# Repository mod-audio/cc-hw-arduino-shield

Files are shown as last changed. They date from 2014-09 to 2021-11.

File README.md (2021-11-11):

control-chain-arduino-shield
============================

This repository contains the schematics and PCB design files for Control Chain Arduino Shield hardware. It serves as a way for people to create new peripheral to be used in conjunction with MOD (http://moddevices.com/) via its Control Chain interface.

These files were created and can be improved with KiCAD, a free software Electronics CAD which is available at http://www.kicad.org/

## Check out instructions ##

This project uses a set of KiCAD symbols and footprints provided by the official KiCad library (https://github.com/KiCad/). In order to properly fetch these dependencies, which are configured as submodule repositories, you have to use the **--recursive** attribute in the following **git** command:

> git clone --recursive https://github.com/portalmod/control-chain-arduino-shield.git

## Licensing ##

This is an Open Hardware project and all of the files in this repository are licensed under the terms of the "Creative Commons By-SA" license.

## Sample Code / Arduino Library ##

There is an Arduino library for making it easy to develop your own Control Chain peripherals freely available at https://github.com/portalmod/control-chain-arduino-lib

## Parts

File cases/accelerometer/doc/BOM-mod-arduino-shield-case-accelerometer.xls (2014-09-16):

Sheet: BOM
VALUE | QTD(x1) | PACKAGE | DESCRIPTION | MANUFACTURER | PART NUMBER
MISC
Accelerometer_MPU6050 | 1 | - | GY-521 MPU6050 3-Axis Acceleration Gyroscope 6DOF Module - Blue | - | http://www.dx.com/p/gy-521-mpu6050-3-axis-acceleration-gyroscope-6dof-module-blue-154602

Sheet: KiCAD
Item | Qty | Reference(s) | Value | LibPart | Footprint | Datasheet
1 | 2 | AD1, AD_PROTO1 | HEADER_1x6 | MODuino_Control_Chain:HEADER_1x6 | HEADER_100MIL_1R6P_PTH
2 | 3 | C1, C7, C9 | 100uF | device:CP1 | CAP_RAD_5MM
3 | 6 | C2, C3, C4, C5, C6, C8 | 100nF | device:C | SM0805
4 | 1 | D1 | CGRA4007-G | device:DIODE | DO-214AC(SMA)
5 | 2 | D2, D3 | MMSZ5242B | device:ZENERsmall | SOD123
6 | 2 | H1, H2 | HOLE | conn:CONN_1 | HOLE_3MM
7 | 2 | IOH1, IOH_PROTO1 | HEADER_1x10 | MODuino_Control_Chain:HEADER_1x10 | HEADER_100MIL_1R10P_PTH
8 | 4 | IOL1, IOL_PROTO1, POWER1, POWER_PROTO1 | HEADER_1x8 | MODuino_Control_Chain:HEADER_1x8 | HEADER_100MIL_1R8P_PTH
9 | 2 | J1, J2 | RJHSE-5084 | MODuino_Control_Chain:RJ45_CHAIN | RJ45-RJHSE5084
10 | 1 | JP1 | HEADER_2x3_180 | MODuino_Control_Chain:HEADER_2x3 | HEADER_100MIL_2R3P_PTH
11 | 1 | PROTOBOARD1 | PROTO_8x16 | MODuino_Control_Chain:PROTO_8x16 | PROTOBOARD_100MIL_8R16P_PTH
12 | 3 | PROTO_3.3V1, PROTO_5V1, PROTO_GND1 | HEADER_1x16 | MODuino_Control_Chain:HEADER_1x16 | PROTOBOARD_100MIL_1R16P_PTH
13 | 2 | Q1, Q2 | MMBT3904 | device:NPN | SOT23
14 | 1 | R1 | 120R | device:R | SM0805
15 | 4 | R10, R4, R5, R9 | 1k | device:R | SM0805
16 | 4 | R11, R12, R13, R14 | 470R | device:R | SM0805
17 | 2 | R2, R3 | 10R | device:R | SM0805
18 | 3 | R6, R7, R8 | 10k | device:R | SM0805
19 | 1 | RT1 | FUSE_500mA | device:FUSE | SM2920
20 | 1 | U1 | SN75176BDR | MODuino_Control_Chain:SN75176BDR | SO8E

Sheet: KiCAD Organized
Value | Qty | Reference(s) | Footprint
CAPACITOR
100nF | 6 | C2, C3, C4, C5, C6, C8 | SM0805
100uF | 3 | C1, C7, C9 | CAP_RAD_5MM
RESISTOR
10R | 2 | R2, R3 | SM0805
120R | 1 | R1 | SM0805
470R | 4 | R11, R12, R13, R14 | SM0805
1k | 4 | R10, R4, R5, R9 | SM0805
10k | 3 | R6, R7, R8 | SM0805
DIODE
CGRA4007-G | 1 | D1 | DO-214AC(SMA)
MMSZ5242B | 2 | D2, D3 | SOD123
TRANSISTOR
MMBT3904 | 2 | Q1, Q2 | SOT23
IC
SN75176BDR | 1 | U1 | SO8E
MISC
FUSE_500mA | 1 | RT1 | SM1210
CONNECTOR
HEADER_1x6 | 2 | AD1, AD_PROTO1 | HEADER_100MIL_1R6P_PTH
HEADER_1x10 | 2 | IOH1, IOH_PROTO1 | HEADER_100MIL_1R10P_PTH
HEADER_1x8 | 4 | IOL1, IOL_PROTO1, POWER1, POWER_PROTO1 | HEADER_100MIL_1R8P_PTH
RJHSE-5084 | 2 | J1, J2 | RJ45-RJHSE5084
HEADER_2x3_180 | 1 | JP1 | HEADER_100MIL_2R3P_PTH
PROTO_8x16 | 1 | PROTOBOARD1 | PROTOBOARD_100MIL_8R16P_PTH
HEADER_1x16 | 3 | PROTO_3.3V1, PROTO_5V1, PROTO_GND1 | PROTOBOARD_100MIL_1R16P_PTH

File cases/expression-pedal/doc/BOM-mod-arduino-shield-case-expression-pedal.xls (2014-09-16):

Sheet: BOM
VALUE | QTD(x1) | PACKAGE | DESCRIPTION | MANUFACTURER | PART NUMBER
RESISTOR
100R | 3 | 0.091" Dia x 0.256" L (2.30mm x 6.50mm) | RES 100 OHM 1/4W 5% CARBON FILM | Stackpole Eletronics Inc | CF14JT100R (http://www.digikey.com/product-detail/en/CF14JT100R/CF14JT100RCT-ND/1830327)
10k | 1 | 0.091" Dia x 0.256" L (2.30mm x 6.50mm) | RES 10K OHM 1/4W 5% CARBON FILM | Stackpole Eletronics Inc | CF14JT10K0 (http://www.digikey.com/product-detail/en/CF14JT10K0/CF14JT10K0CT-ND/1830374)
POT 10k | 1 | Round - 0.669" Dia x 0.374" L (17.00mm x 9.50mm) | POT ROTARY 10K OHM 16MM PC PIN | TT Eletronics/BI | P160KN2-4QC20B10K (http://www.digikey.com/product-detail/en/P160KN2-4QC20B10K/987-1310-ND/2408887)
MISC
Switch Button | 1 | Through Hole | Pushbutton Switches DPDT STOMP/FOOT SW LATCH 4A30VDC 9LUG | Alpha | SF12020F-0202-20R-L-011 (http://br.mouser.com/ProductDetail/Alpha-Taiwan/SF12020F-0202-20R-L-011/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)

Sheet: KiCAD
Item | Qty | Reference(s) | Value | LibPart | Footprint | Datasheet
1 | 2 | AD1, AD_PROTO1 | HEADER_1x6 | MODuino_Control_Chain:HEADER_1x6 | HEADER_100MIL_1R6P_PTH
2 | 3 | C1, C7, C9 | 100uF | device:CP1 | CAP_RAD_5MM
3 | 6 | C2, C3, C4, C5, C6, C8 | 100nF | device:C | SM0805
4 | 1 | D1 | CGRA4007-G | device:DIODE | DO-214AC(SMA)
5 | 2 | D2, D3 | MMSZ5242B | device:ZENERsmall | SOD123
6 | 2 | H1, H2 | HOLE | conn:CONN_1 | HOLE_3MM
7 | 2 | IOH1, IOH_PROTO1 | HEADER_1x10 | MODuino_Control_Chain:HEADER_1x10 | HEADER_100MIL_1R10P_PTH
8 | 4 | IOL1, IOL_PROTO1, POWER1, POWER_PROTO1 | HEADER_1x8 | MODuino_Control_Chain:HEADER_1x8 | HEADER_100MIL_1R8P_PTH
9 | 2 | J1, J2 | RJHSE-5084 | MODuino_Control_Chain:RJ45_CHAIN | RJ45-RJHSE5084
10 | 1 | JP1 | HEADER_2x3_180 | MODuino_Control_Chain:HEADER_2x3 | HEADER_100MIL_2R3P_PTH
11 | 1 | PROTOBOARD1 | PROTO_8x16 | MODuino_Control_Chain:PROTO_8x16 | PROTOBOARD_100MIL_8R16P_PTH
12 | 3 | PROTO_3.3V1, PROTO_5V1, PROTO_GND1 | HEADER_1x16 | MODuino_Control_Chain:HEADER_1x16 | PROTOBOARD_100MIL_1R16P_PTH
13 | 2 | Q1, Q2 | MMBT3904 | device:NPN | SOT23
14 | 1 | R1 | 120R | device:R | SM0805
15 | 4 | R10, R4, R5, R9 | 1k | device:R | SM0805
16 | 4 | R11, R12, R13, R14 | 470R | device:R | SM0805
17 | 2 | R2, R3 | 10R | device:R | SM0805
18 | 3 | R6, R7, R8 | 10k | device:R | SM0805
19 | 1 | RT1 | FUSE_500mA | device:FUSE | SM2920
20 | 1 | U1 | SN75176BDR | MODuino_Control_Chain:SN75176BDR | SO8E

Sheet: KiCAD Organized
Value | Qty | Reference(s) | Footprint
CAPACITOR
100nF | 6 | C2, C3, C4, C5, C6, C8 | SM0805
100uF | 3 | C1, C7, C9 | CAP_RAD_5MM
RESISTOR
10R | 2 | R2, R3 | SM0805
120R | 1 | R1 | SM0805
470R | 4 | R11, R12, R13, R14 | SM0805
1k | 4 | R10, R4, R5, R9 | SM0805
10k | 3 | R6, R7, R8 | SM0805
DIODE
CGRA4007-G | 1 | D1 | DO-214AC(SMA)
MMSZ5242B | 2 | D2, D3 | SOD123
TRANSISTOR
MMBT3904 | 2 | Q1, Q2 | SOT23
IC
SN75176BDR | 1 | U1 | SO8E
MISC
FUSE_500mA | 1 | RT1 | SM1210
CONNECTOR
HEADER_1x6 | 2 | AD1, AD_PROTO1 | HEADER_100MIL_1R6P_PTH
HEADER_1x10 | 2 | IOH1, IOH_PROTO1 | HEADER_100MIL_1R10P_PTH
HEADER_1x8 | 4 | IOL1, IOL_PROTO1, POWER1, POWER_PROTO1 | HEADER_100MIL_1R8P_PTH
RJHSE-5084 | 2 | J1, J2 | RJ45-RJHSE5084
HEADER_2x3_180 | 1 | JP1 | HEADER_100MIL_2R3P_PTH
PROTO_8x16 | 1 | PROTOBOARD1 | PROTOBOARD_100MIL_8R16P_PTH
HEADER_1x16 | 3 | PROTO_3.3V1, PROTO_5V1, PROTO_GND1 | PROTOBOARD_100MIL_1R16P_PTH

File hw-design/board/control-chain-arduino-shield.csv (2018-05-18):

Item | Qty | Reference(s) | Value | LibPart | Footprint | Datasheet | MPN | Note
1 | 1 | C1 | 10uF | device:CP1 | Capacitors_SMD:c_elec_5x5.3 |  | UWX1E100MCL1GB
2 | 2 | C2, C3 | 100nF | device:C | Capacitors_SMD:C_0603 |  | C1608X7R1E104K080AA
3 | 1 | C4 | 10uF | device:C | Capacitors_SMD:C_0603 |  | GRM188R60G106ME47D
4 | 1 | D1 | CGRA4007-G | device:D | Diodes_SMD:Diode-SMA_Standard |  | CGRA4007-G
5 | 1 | D2 | LED | device:LED | LEDs:LED-0603 |  | LS Q976-NR-1
6 | 3 | D3, D4, D5 | 1N4148 | device:D | Diodes_SMD:SOD-323 |  | 1N4148WX-TP
7 | 1 | J1 | CC_MAIN | conn:RJ45 | local-footprints:54602-908LF |  | 54602-908LF
8 | 1 | J2 | CC_NEXT | conn:RJ45 | local-footprints:54602-908LF |  | 54602-908LF
9 | 1 | P1 | Power | conn:CONN_01X08 | Socket_Arduino_Uno:Socket_Strip_Arduino_1x08 |  | PREC008SFAN-RC
10 | 1 | P10 | Power | conn:CONN_01X08 | Socket_Arduino_Uno:Socket_Strip_Arduino_1x08 |  |  | no component
11 | 1 | P11 | Analog | conn:CONN_01X06 | Socket_Arduino_Uno:Socket_Strip_Arduino_1x06 |  |  | no component
12 | 1 | P12 | Digital | conn:CONN_01X10 | Socket_Arduino_Uno:Socket_Strip_Arduino_1x10 |  |  | no component
13 | 1 | P13 | Digital | conn:CONN_01X08 | Socket_Arduino_Uno:Socket_Strip_Arduino_1x08 |  |  | no component
14 | 5 | P14, P19, P20, P21, P9 | ~ | conn:CONN_01X14 | Socket_Arduino_Uno:Perfboard |  |  | no component
15 | 1 | P2 | Analog | conn:CONN_01X06 | Socket_Arduino_Uno:Socket_Strip_Arduino_1x06 |  | PREC006SFAN-RC
16 | 1 | P3 | Digital | conn:CONN_01X10 | Socket_Arduino_Uno:Socket_Strip_Arduino_1x10 |  | PREC010SFAN-RC
17 | 1 | P4 | Digital | conn:CONN_01X08 | Socket_Arduino_Uno:Socket_Strip_Arduino_1x08 |  | PREC008SFAN-RC
18 | 4 | P5, P6, P7, P8 | Hole | conn:CONN_01X01 | Socket_Arduino_Uno:Arduino_1pin |  |  | no component
19 | 2 | Q1, Q2 | 2N7002 | device:Q_NMOS_GSD | Housings_SOT-23_SOT-143_TSOT-6:SOT-23 |  | 2N7002P,215
20 | 1 | Q4 | IRFML8244TRPBF | device:Q_NMOS_GSD | Housings_SOT-23_SOT-143_TSOT-6:SOT-23 |  | IRFML8244TRPBF
21 | 1 | R1 | 330R | device:R | Resistors_SMD:R_0603 |  | RMCF0603JT330R
22 | 5 | R10, R11, R2, R4, R8 | 10K | device:R | Resistors_SMD:R_0603 |  | RMCF0603JT10K0
23 | 1 | R3 | 220K | device:R | Resistors_SMD:R_0603 |  | RMCF0603JT220K
24 | 1 | R9 | 100R | device:R | Resistors_SMD:R_0805 |  | ERJ-P06F1000V
25 | 1 | RT1 | PTC_FUSE | device:FUSE | Resistors_SMD:R_1210 |  | 0ZCB0050FF2G
26 | 1 | U1 | ISL83491 | interface:ISL83491 | Housings_SOIC:SOIC-14_3.9x8.7mm_Pitch1.27mm |  | ISL83491IBZ

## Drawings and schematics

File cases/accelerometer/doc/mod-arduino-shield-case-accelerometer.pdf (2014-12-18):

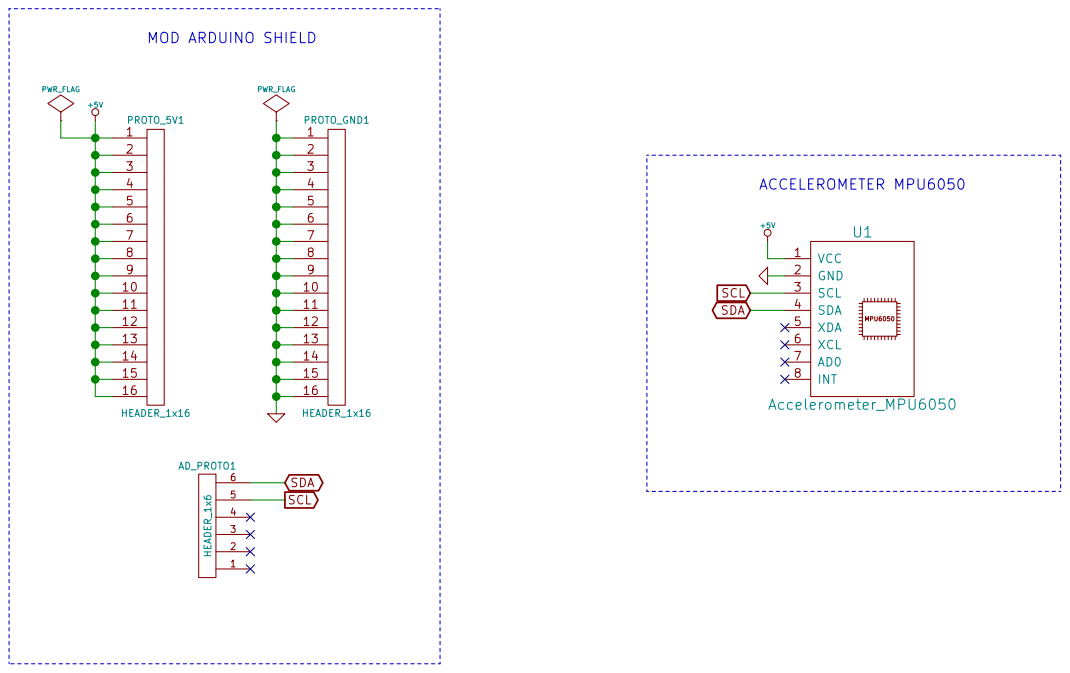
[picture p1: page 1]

File: mod-arduino-shield-case-accelerometer.sch Sheet: / http://portalmod.com/

Id: 1/1 Title: Accelerometer example circuit for the MOD Arduino Shield

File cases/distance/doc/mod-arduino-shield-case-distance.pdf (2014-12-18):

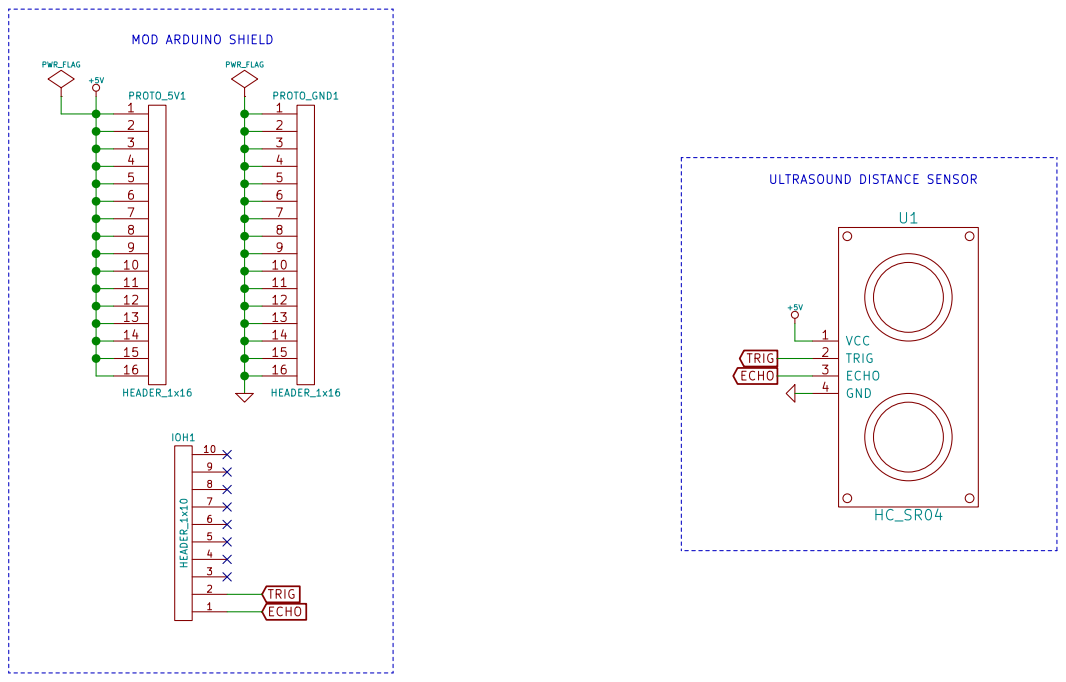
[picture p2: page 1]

ULTRASOUND DISTANCE SENSOR MOD ARDUINO SHIELD
PROTO_GND1 HEADER_1x16

File: mod-arduino-shield-case-distance.sch Sheet: / http://portalmod.com/

Id: 1/1 Title: Ultrasound Distance example circuit for the MOD Arduino Shield

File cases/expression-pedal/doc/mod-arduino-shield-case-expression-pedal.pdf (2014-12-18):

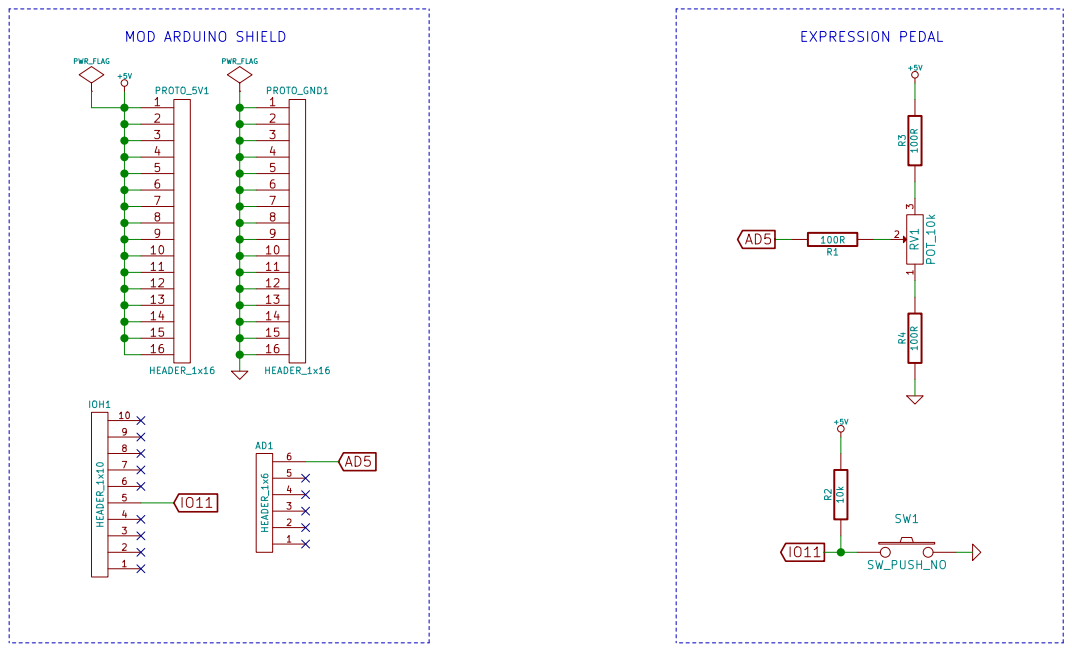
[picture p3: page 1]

File: mod-arduino-shield-case-expression-pedal.sch Sheet: / http://portalmod.com/

Id: 1/1 Title: Expression Pedal example circuit for the MOD Arduino Shield

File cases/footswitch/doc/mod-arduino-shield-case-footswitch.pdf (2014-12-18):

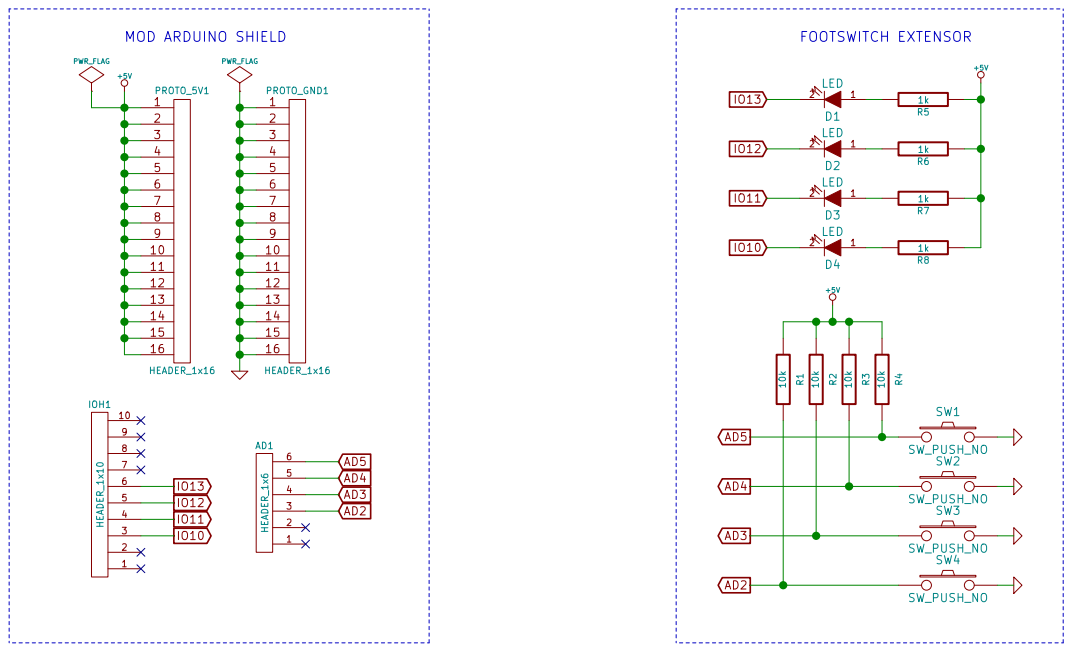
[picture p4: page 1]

File: mod-arduino-shield-case-footswitch.sch Sheet: / http://portalmod.com/

Id: 1/1 Title: Footswitch Extensor example circuit for the MOD Arduino Shield

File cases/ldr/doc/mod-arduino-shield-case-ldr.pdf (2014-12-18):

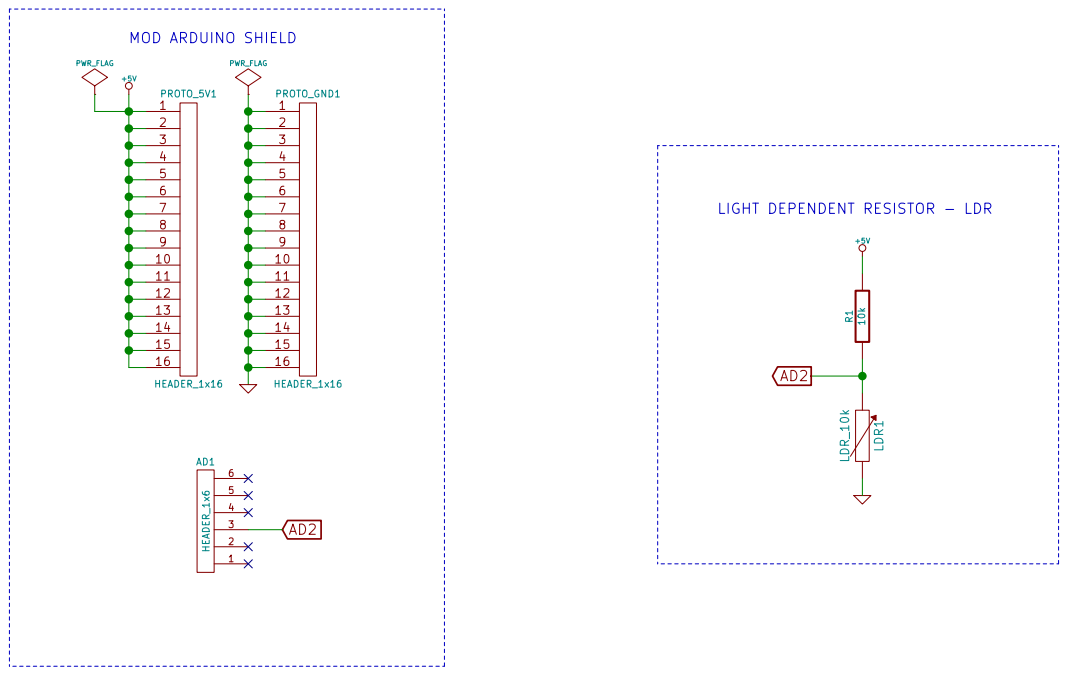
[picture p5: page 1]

LIGHT DEPENDENT RESISTOR - LDR LDR1 LDR_10k

File: mod-arduino-shield-case-ldr.sch Sheet: / http://portalmod.com/

Id: 1/1 Title: Light Sensor example circuit for the MOD Arduino Shield

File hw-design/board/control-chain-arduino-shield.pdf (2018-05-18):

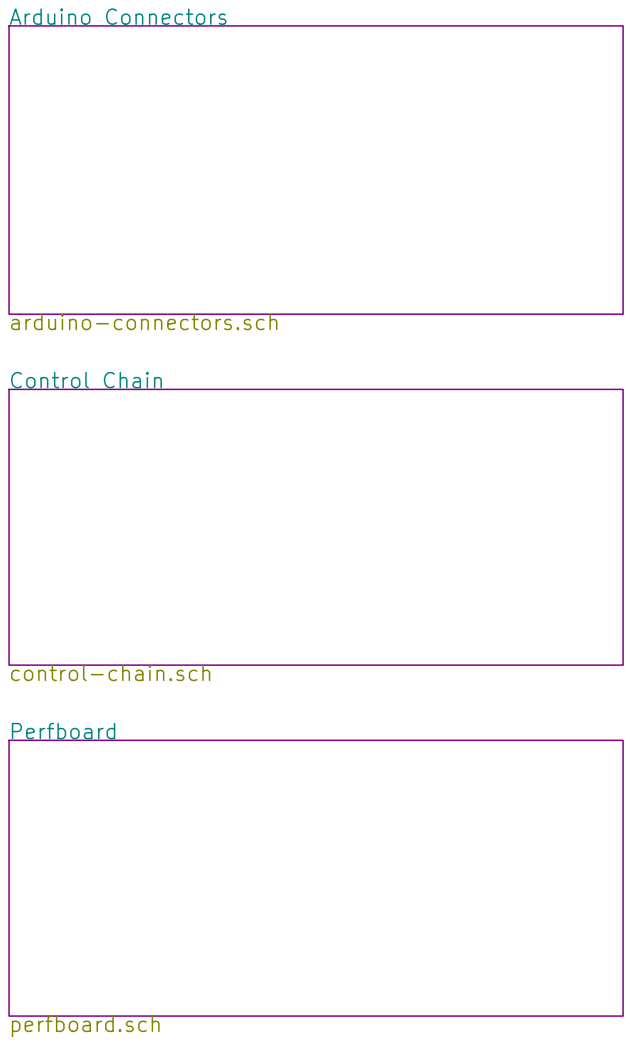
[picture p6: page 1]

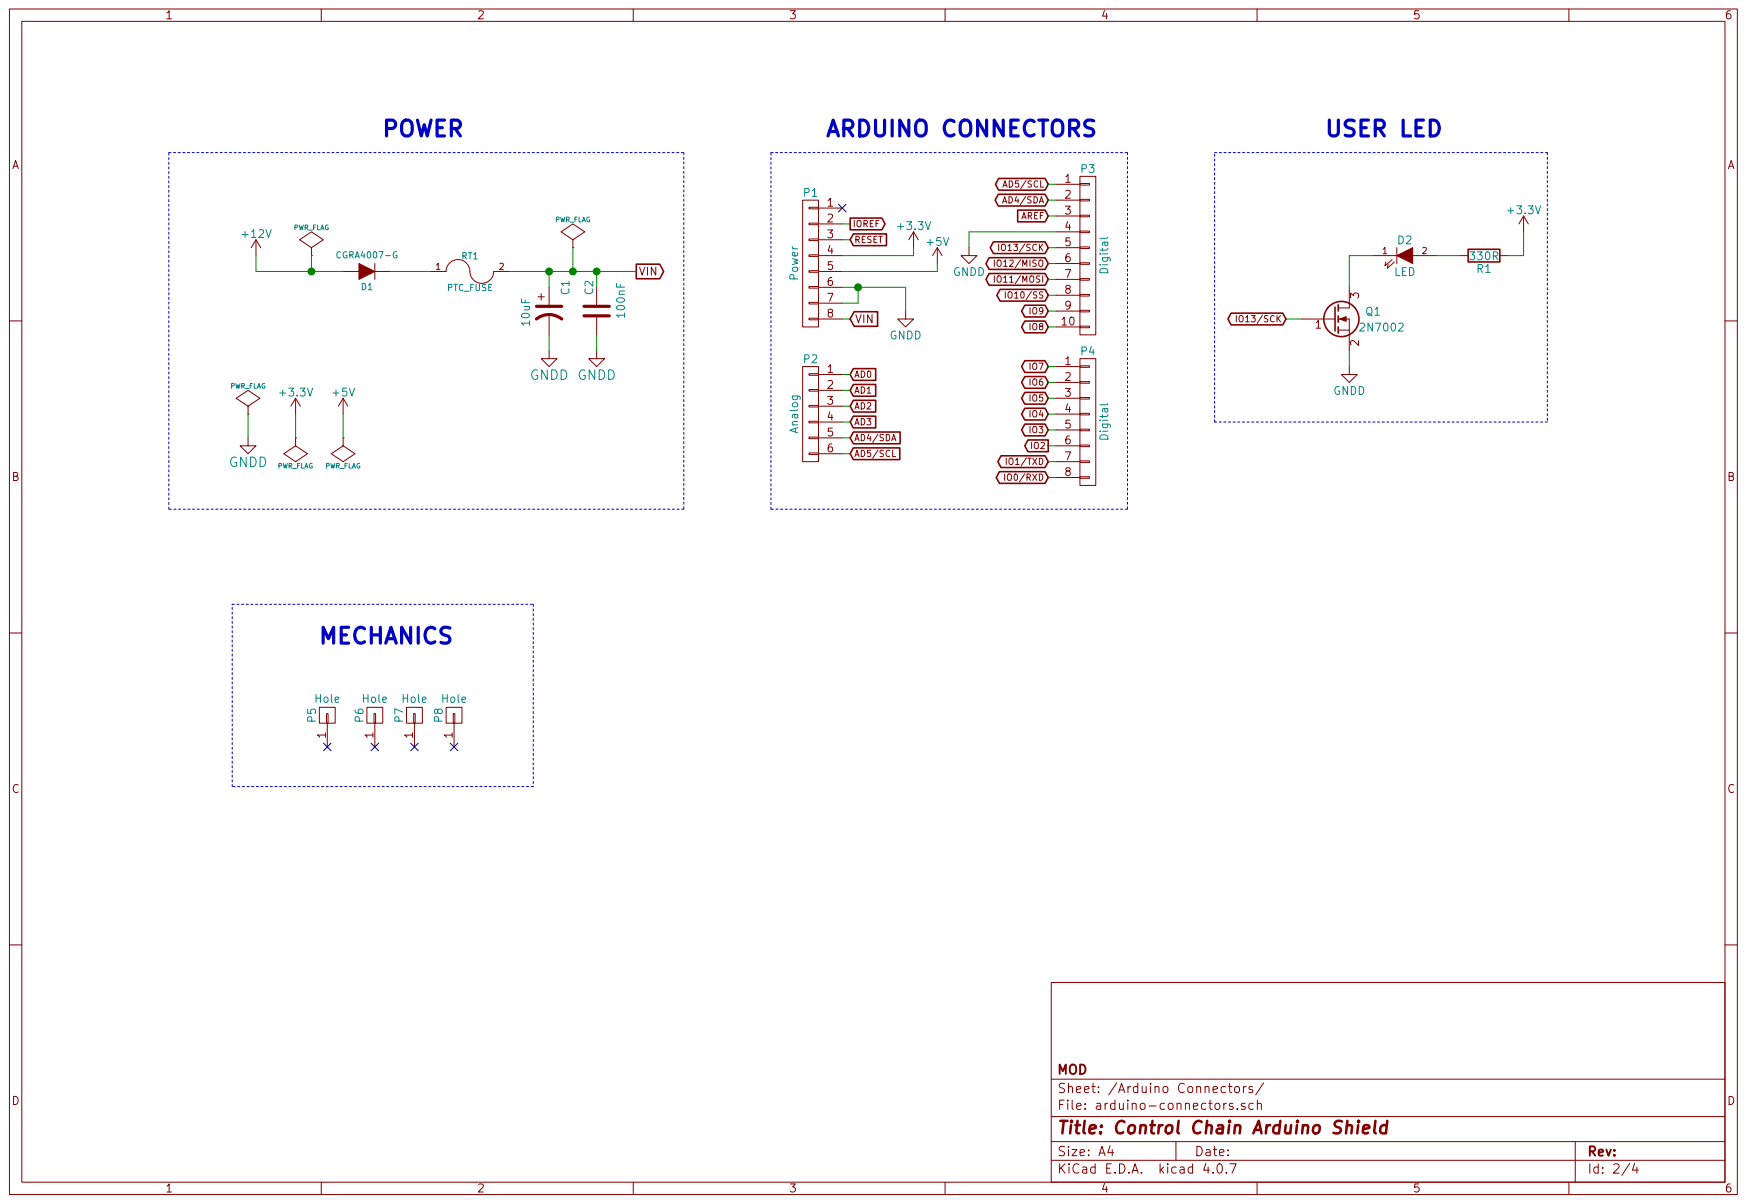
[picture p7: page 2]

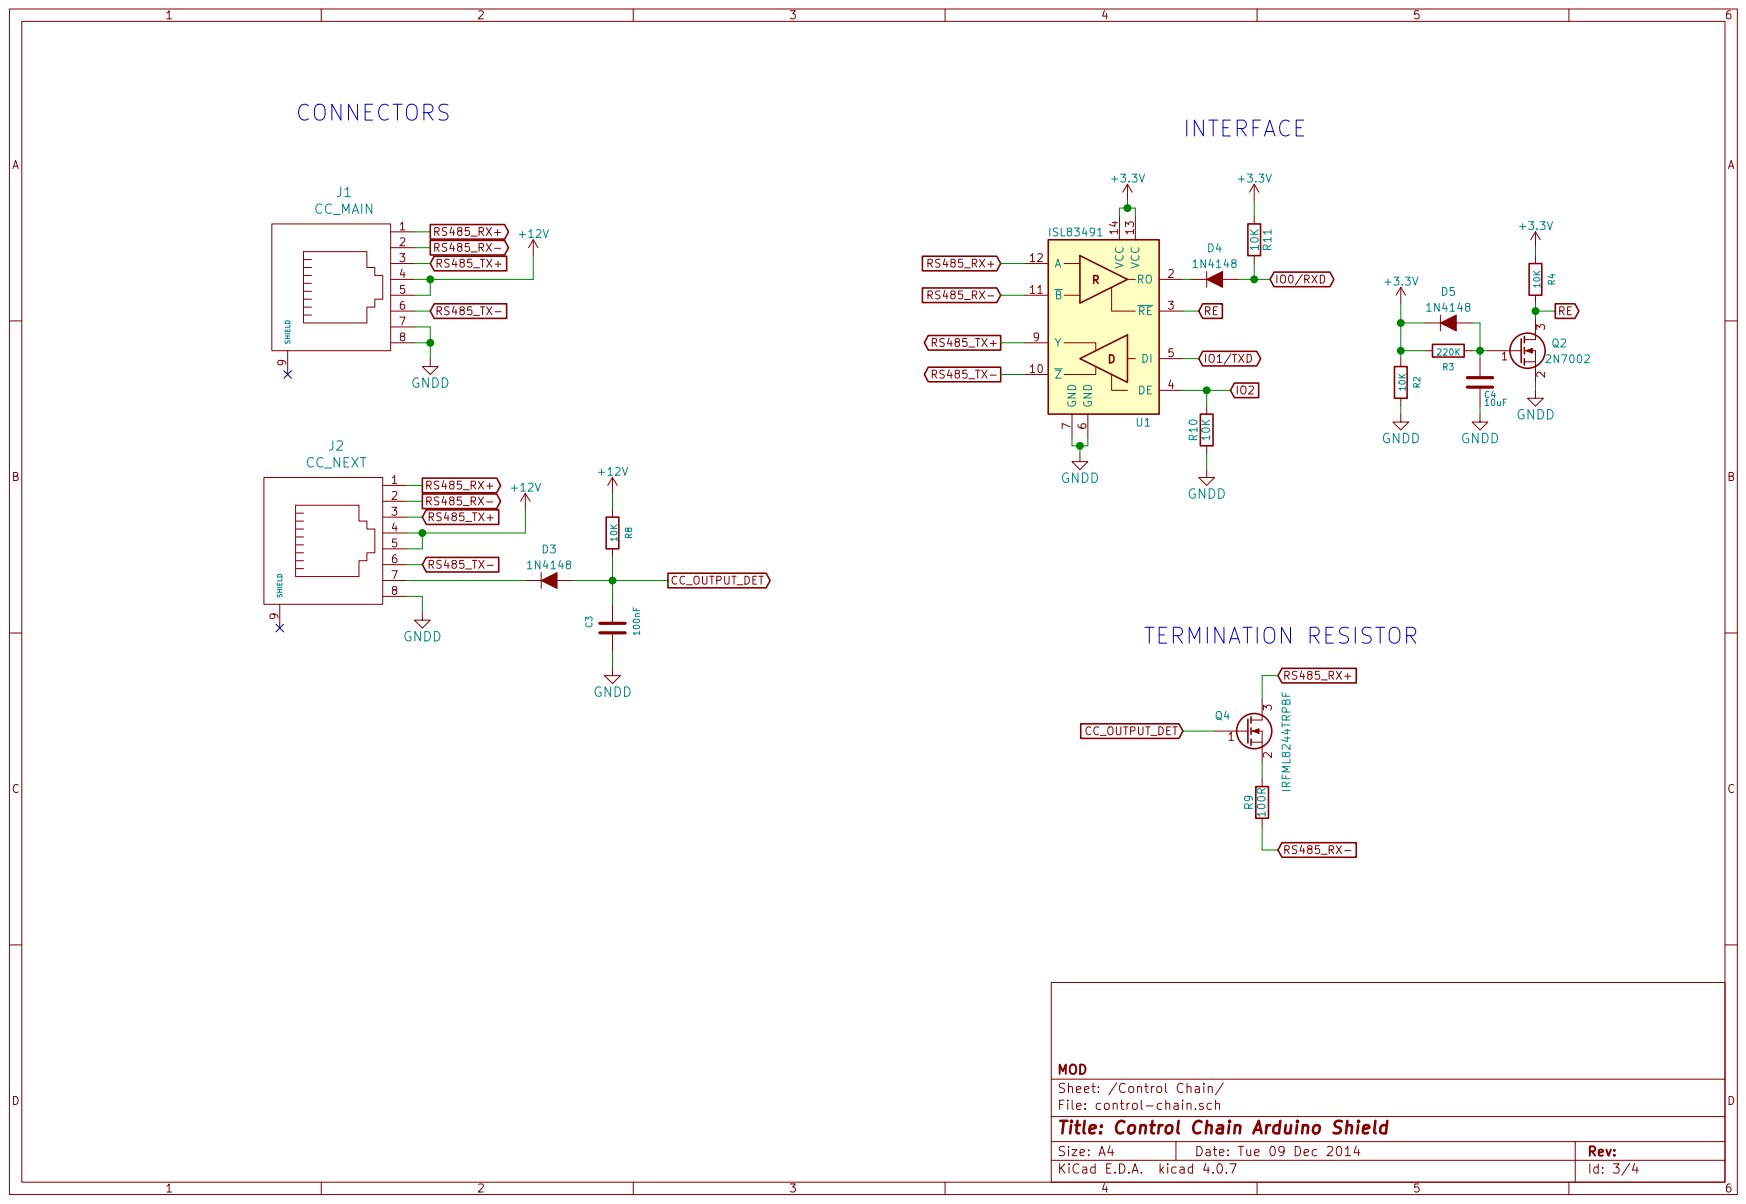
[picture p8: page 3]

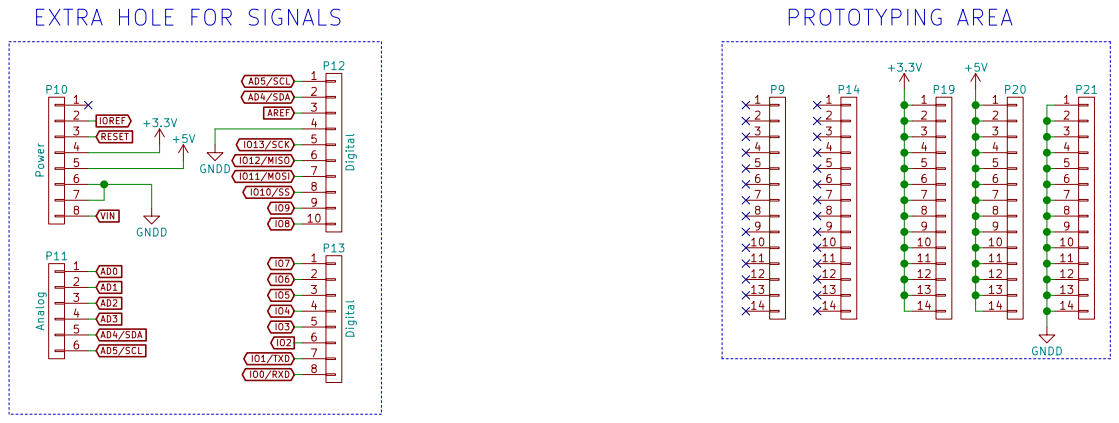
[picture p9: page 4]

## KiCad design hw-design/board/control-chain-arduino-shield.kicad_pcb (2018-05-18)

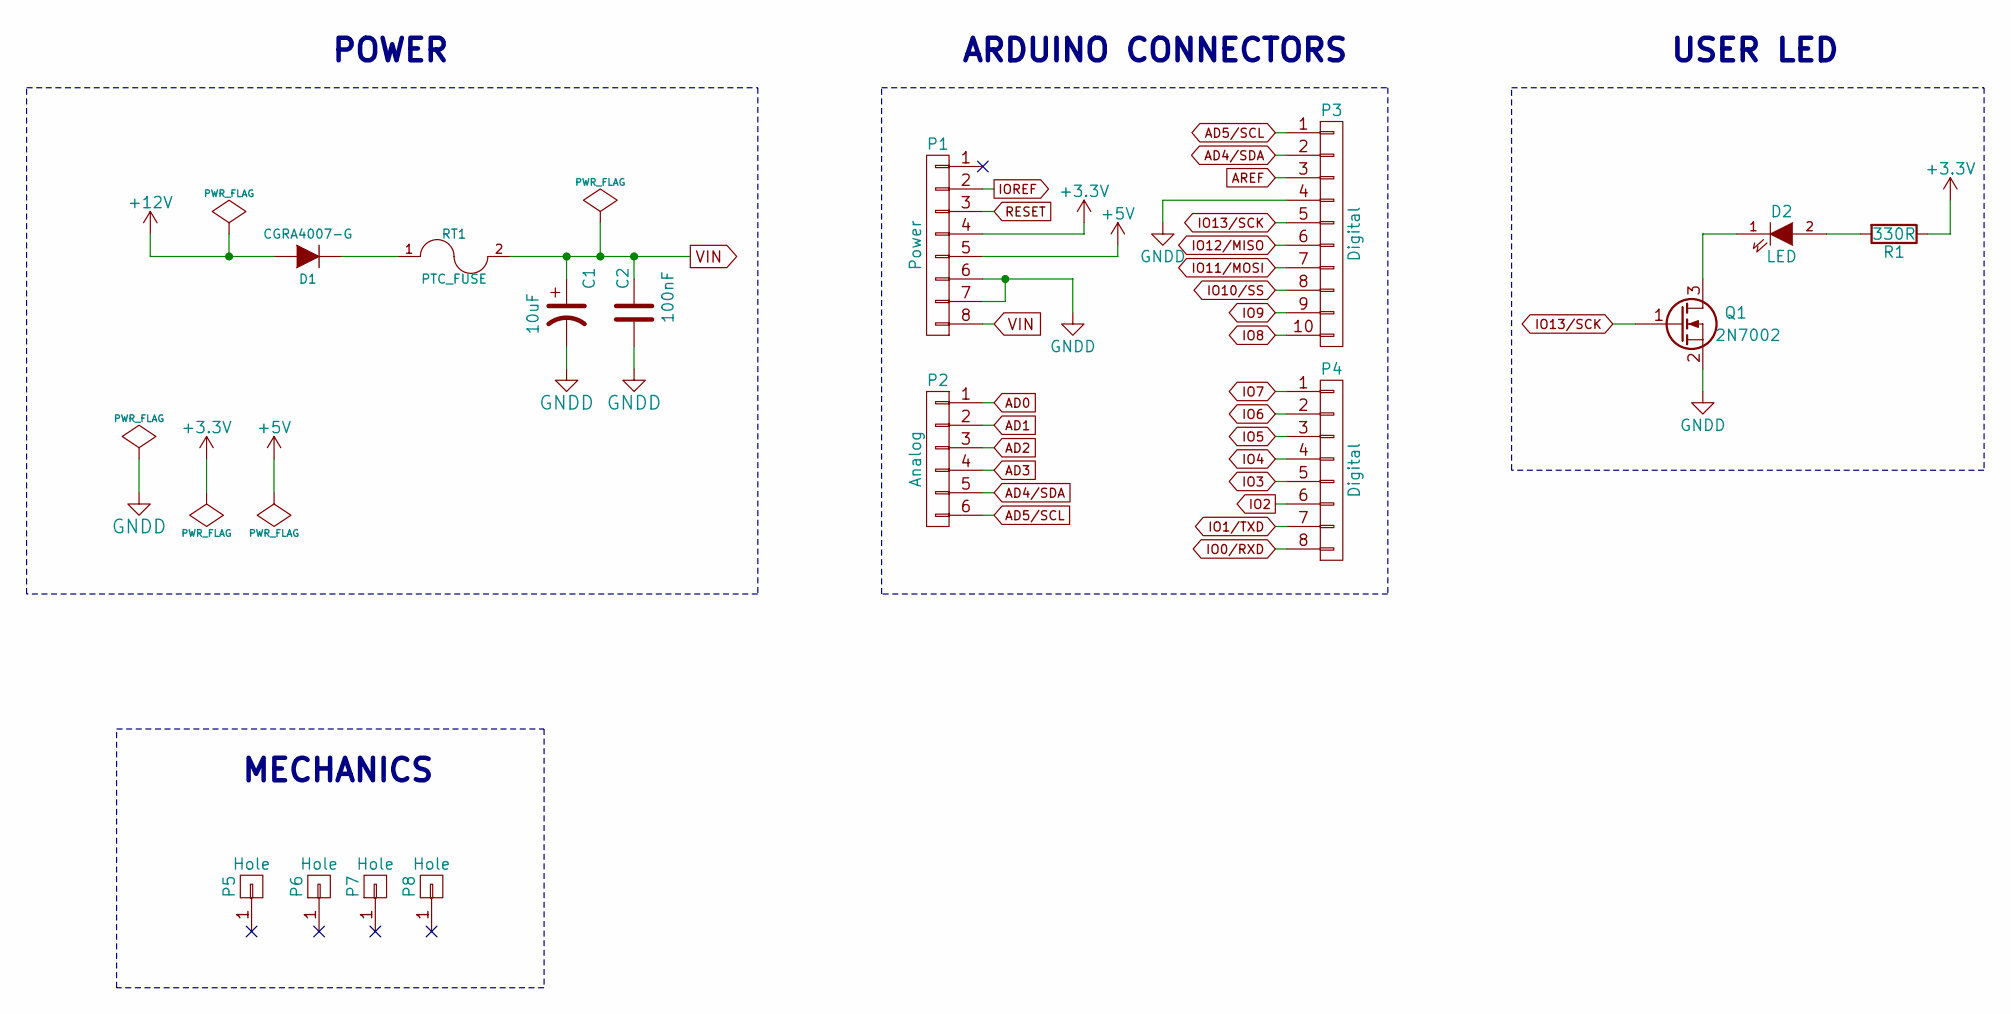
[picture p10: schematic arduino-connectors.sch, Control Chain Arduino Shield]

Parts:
C1: 10uF; c_elec_5x5.3; MPN UWX1E100MCL1GB
C2: 100nF; C_0603; MPN C1608X7R1E104K080AA
D1: CGRA4007-G; Diode-SMA_Standard; MPN CGRA4007-G
D2: LED; LED-0603; MPN LS Q976-NR-1
P1: Power; Socket_Strip_Arduino_1x08; MPN PREC008SFAN-RC
P2: Analog; Socket_Strip_Arduino_1x06; MPN PREC006SFAN-RC
P3: Digital; Socket_Strip_Arduino_1x10; MPN PREC010SFAN-RC
P4: Digital; Socket_Strip_Arduino_1x08; MPN PREC008SFAN-RC
P5, P6, P7, P8: Hole; Arduino_1pin
Q1: 2N7002; SOT-23; MPN 2N7002P,215
R1: 330R; R_0603; MPN RMCF0603JT330R
RT1: PTC_FUSE; R_1210; MPN 0ZCB0050FF2G

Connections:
+3V3: P1.4, R1.1; also elsewhere on the board
+5V: P1.5; also elsewhere on the board
+12V: D1.2 (A); also elsewhere on the board
AD0: P2.1; also elsewhere on the board
AD1: P2.2; also elsewhere on the board
AD2: P2.3; also elsewhere on the board
AD3: P2.4; also elsewhere on the board
AD4/SDA: P2.5, P3.2; also elsewhere on the board
AD5/SCL: P2.6, P3.1; also elsewhere on the board
AREF: P3.3; also elsewhere on the board
GNDD: C1.2, C2.2, P1.6, P1.7, P3.4, Q1.2 (S); also elsewhere on the board
IO0/RXD: P4.8; also elsewhere on the board
IO1/TXD: P4.7; also elsewhere on the board
IO2: P4.6; also elsewhere on the board
IO3: P4.5; also elsewhere on the board
IO4: P4.4; also elsewhere on the board
IO5: P4.3; also elsewhere on the board
IO6: P4.2; also elsewhere on the board
IO7: P4.1; also elsewhere on the board
IO8: P3.10; also elsewhere on the board
IO9: P3.9; also elsewhere on the board
IO10/SS: P3.8; also elsewhere on the board
IO11/MOSI: P3.7; also elsewhere on the board
IO12/MISO: P3.6; also elsewhere on the board
IO13/SCK: P3.5, Q1.1 (G); also elsewhere on the board
IOREF: P1.2; also elsewhere on the board
unnamed: D1.1 (K), RT1.1
unnamed: D2.1 (K), Q1.3 (D)
unnamed: D2.2 (A), R1.2
RESET: P1.3; also elsewhere on the board
VIN: C1.1, C2.1, P1.8, RT1.2; also elsewhere on the board

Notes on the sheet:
POWER
ARDUINO CONNECTORS
USER LED
MECHANICS

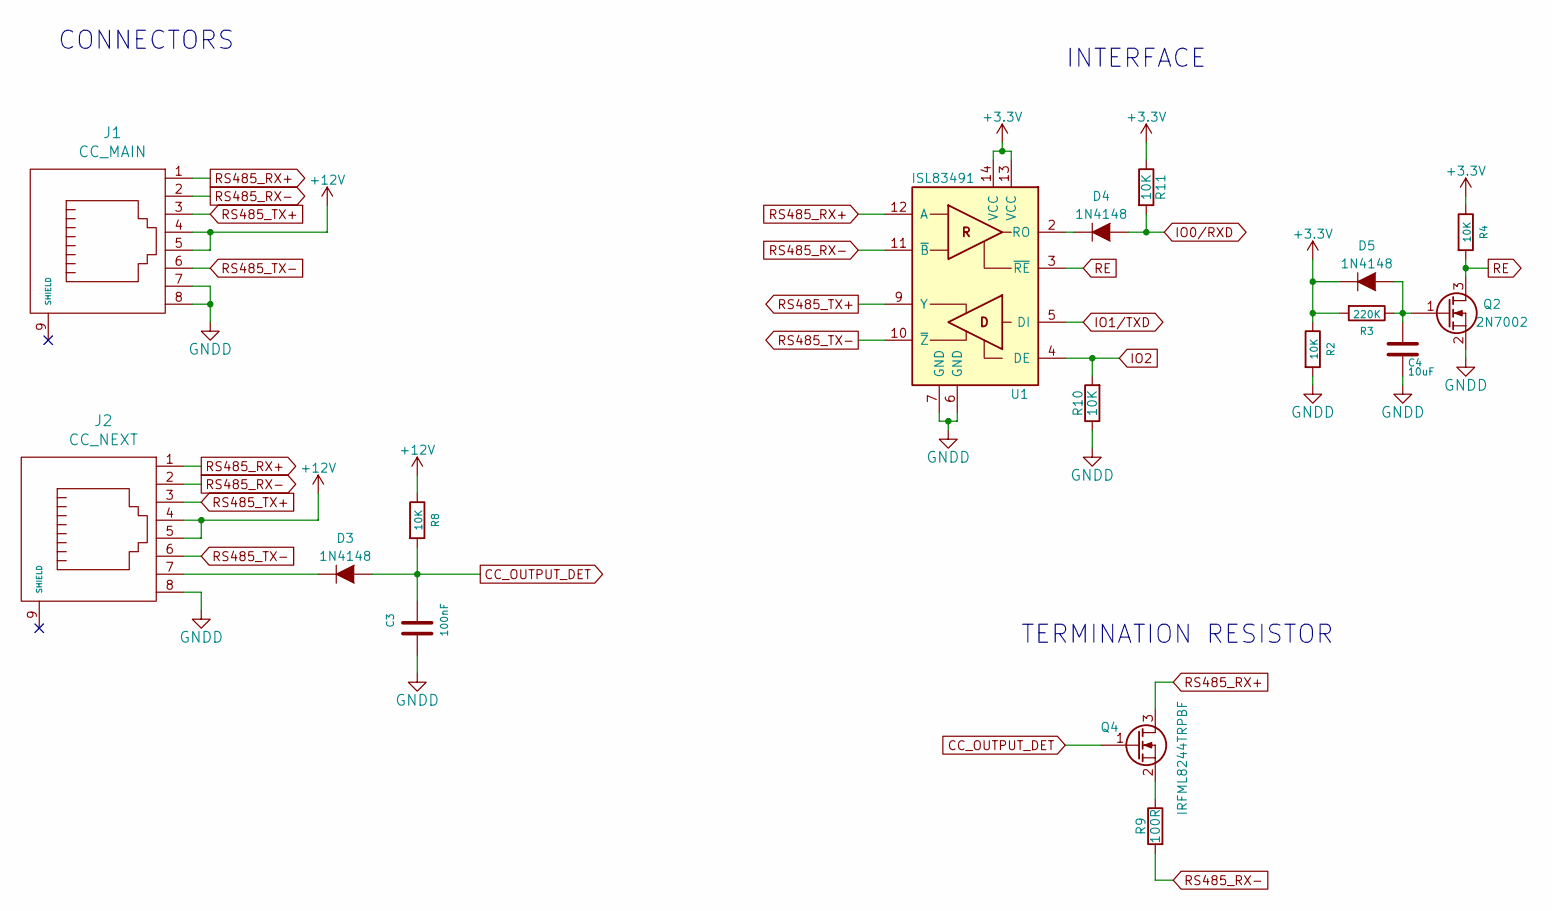
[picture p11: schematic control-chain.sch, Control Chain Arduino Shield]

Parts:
C3: 100nF; C_0603; MPN C1608X7R1E104K080AA
C4: 10uF; C_0603; MPN GRM188R60G106ME47D
D3, D4, D5: 1N4148; SOD-323; MPN 1N4148WX-TP
J1: CC_MAIN; 54602-908LF; MPN 54602-908LF
J2: CC_NEXT; 54602-908LF; MPN 54602-908LF
Q2: 2N7002; SOT-23; MPN 2N7002P,215
Q4: IRFML8244TRPBF; SOT-23; MPN IRFML8244TRPBF
R2, R4, R8, R10, R11: 10K; R_0603; MPN RMCF0603JT10K0
R3: 220K; R_0603; MPN RMCF0603JT220K
R9: 100R; R_0805; MPN ERJ-P06F1000V
U1: ISL83491; SOIC-14_3.9x8.7mm_Pitch1.27mm; MPN ISL83491IBZ

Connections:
+3V3: D5.1 (K), R2.1, R3.2, R4.1, R11.1, U1.13 (VCC), U1.14 (VCC); also elsewhere on the board
+12V: J1.4, J1.5, J2.4, J2.5, R8.1; also elsewhere on the board
CC_OUTPUT_DET: C3.1, D3.2 (A), Q4.1 (G), R8.2
GNDD: C3.2, C4.2, J1.7, J1.8, J2.8, Q2.2 (S), R2.2, R10.1, U1.6 (GND), U1.7 (GND); also elsewhere on the board
IO0/RXD: D4.2 (A), R11.2; also elsewhere on the board
IO1/TXD: U1.5 (DI); also elsewhere on the board
IO2: R10.2, U1.4 (DE); also elsewhere on the board
unnamed: C4.1, D5.2 (A), Q2.1 (G), R3.1
unnamed: D3.1 (K), J2.7
unnamed: D4.1 (K), U1.2 (RO)
unnamed: Q4.2 (S), R9.1
RE: Q2.3 (D), R4.2, U1.3 (~RE)
RS485_RX+: J1.1, J2.1, Q4.3 (D), U1.12 (A)
RS485_RX-: J1.2, J2.2, R9.2, U1.11 (~B)
RS485_TX+: J1.3, J2.3, U1.9 (Y)
RS485_TX-: J1.6, J2.6, U1.10 (~Z~)

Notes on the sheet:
TERMINATION RESISTOR
CONNECTORS
INTERFACE

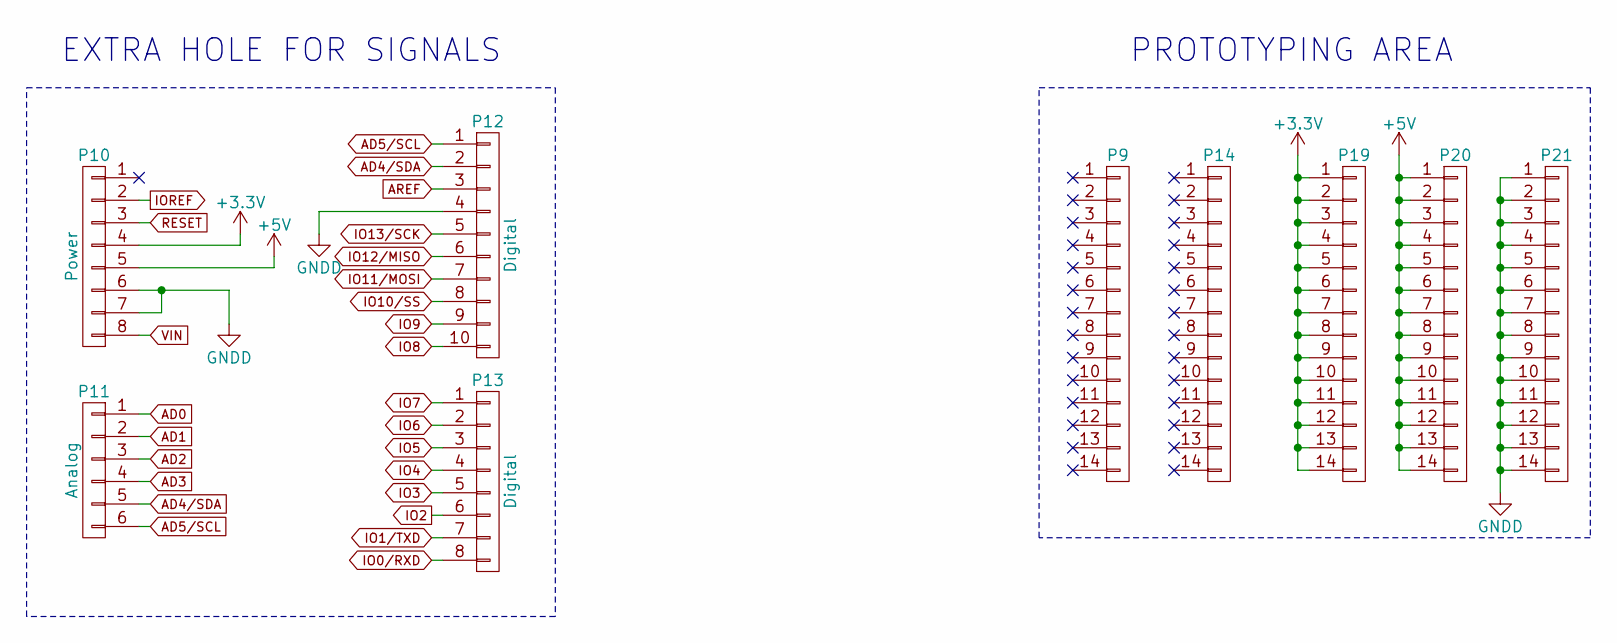
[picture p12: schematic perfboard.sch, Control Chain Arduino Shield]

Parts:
P9, P14: Perfboard
P10: Power; Socket_Strip_Arduino_1x08
P11: Analog; Socket_Strip_Arduino_1x06
P12: Digital; Socket_Strip_Arduino_1x10
P13: Digital; Socket_Strip_Arduino_1x08
P19, P20, P21: Pin_Header_Straight_1x14

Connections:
+3V3: P10.4, P19.1, P19.2, P19.3, P19.4, P19.5, P19.6, P19.7, P19.8, P19.9, P19.10, P19.11, P19.12, P19.13, P19.14; also elsewhere on the board
+5V: P10.5, P20.1, P20.2, P20.3, P20.4, P20.5, P20.6, P20.7, P20.8, P20.9, P20.10, P20.11, P20.12, P20.13, P20.14; also elsewhere on the board
AD0: P11.1; also elsewhere on the board
AD1: P11.2; also elsewhere on the board
AD2: P11.3; also elsewhere on the board
AD3: P11.4; also elsewhere on the board
AD4/SDA: P11.5, P12.2; also elsewhere on the board
AD5/SCL: P11.6, P12.1; also elsewhere on the board
AREF: P12.3; also elsewhere on the board
GNDD: P10.6, P10.7, P12.4, P21.1, P21.2, P21.3, P21.4, P21.5, P21.6, P21.7, P21.8, P21.9, P21.10, P21.11, P21.12, P21.13, P21.14; also elsewhere on the board
IO0/RXD: P13.8; also elsewhere on the board
IO1/TXD: P13.7; also elsewhere on the board
IO2: P13.6; also elsewhere on the board
IO3: P13.5; also elsewhere on the board
IO4: P13.4; also elsewhere on the board
IO5: P13.3; also elsewhere on the board
IO6: P13.2; also elsewhere on the board
IO7: P13.1; also elsewhere on the board
IO8: P12.10; also elsewhere on the board
IO9: P12.9; also elsewhere on the board
IO10/SS: P12.8; also elsewhere on the board
IO11/MOSI: P12.7; also elsewhere on the board
IO12/MISO: P12.6; also elsewhere on the board
IO13/SCK: P12.5; also elsewhere on the board
IOREF: P10.2; also elsewhere on the board
RESET: P10.3; also elsewhere on the board
VIN: P10.8; also elsewhere on the board

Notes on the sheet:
EXTRA HOLE FOR SIGNALS
PROTOTYPING AREA

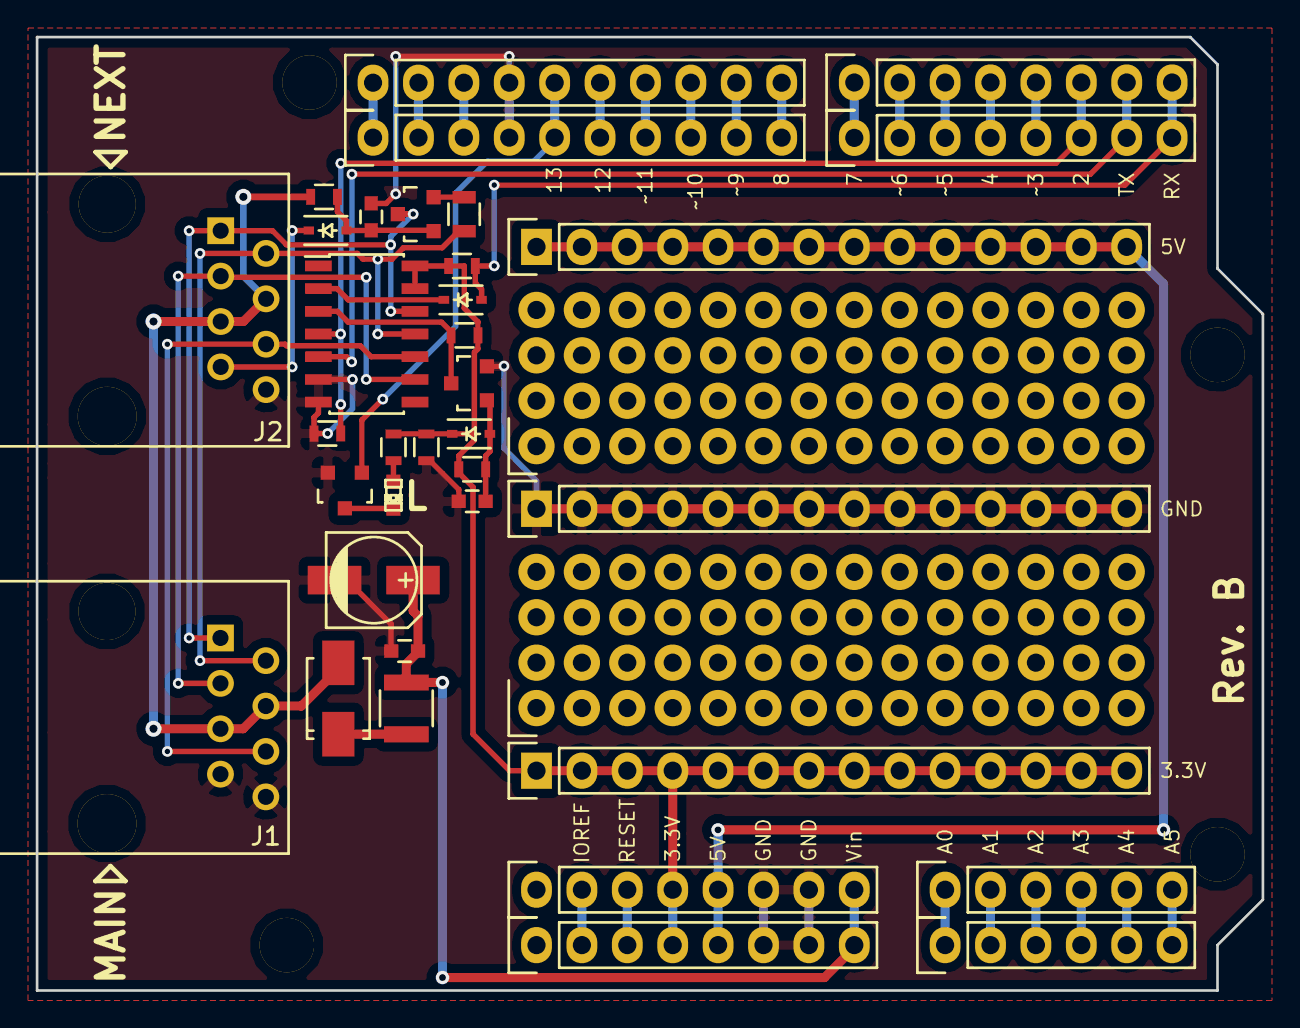
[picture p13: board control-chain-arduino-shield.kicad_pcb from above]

Board: 2 copper layers, 68.6 x 53.3 mm, 41 parts (0 on the bottom side), 41 nets.

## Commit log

2014-09-16 Initial commit for MOD Arduino Shield. Shield for interfacing the Arduino to the Control Chain of MOD. Opening the hardware for the community.
    [BOM-mod-arduino-shield-case-accelerometer.xls, BOM-mod-arduino-shield-case-distance.xls, BOM-mod-arduino-shield-case-expression-pedal.xls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]
2014-12-02 Adding a few footprints exported from the footswitch repository that were using the old library file format (.mod).
2014-12-02 replacing specific references and values in the footprints by generic ones
2014-12-04 Adding metadata to the schematics of the example circuits.
    [mod-arduino-shield-case-accelerometer.sch, mod-arduino-shield-case-distance.sch, mod-arduino-shield-case-expression-pedal.sch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]
2014-12-04 removing local copy of footprints and adding the mod-kicad-footprints repository as a submodule dependency
    [mod-arduino-shield.sch]
2014-12-04 updating component => footprint mapping file to use the new footprint library
2014-12-04 improving the README and pointing users to the repository containing sample code and the arduino library (fix issue #5)
2014-12-04 add metadata and licensing info to the schematics file (fix issue #4)
    [mod-arduino-shield.sch]
2014-12-09 fix issue #3: Add "CC by-SA" license logo to the PCB silk layer Added MOD logo and improved/rearranged previous silk text.
    [mod-arduino-shield-B_Cu.gbl, mod-arduino-shield-B_Mask.gbs, mod-arduino-shield-B_SilkS.gbo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]
2014-12-09 fix issue #6: use same labels on shield as used in arduino
    [mod-arduino-shield-B_Cu.gbl, mod-arduino-shield-B_Mask.gbs, mod-arduino-shield-B_SilkS.gbo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]
2014-12-09 fix issue #2: rename VCCIO to IOREF
    [mod-arduino-shield-B_Cu.gbl, mod-arduino-shield-B_Mask.gbs, mod-arduino-shield-B_SilkS.gbo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]
2014-12-09 fix issue #1: IOREF should not be used to power the circuit
    [mod-arduino-shield-B_Cu.gbl, mod-arduino-shield-B_Mask.gbs, mod-arduino-shield-B_SilkS.gbo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]
2014-12-18 plotting the schematics to PDF files to be kept in the /docs directories (we should always update these PDF files when we make changes to the schematics).
2015-06-25 added hw-design directory
    [arduino-connectors.sch, control-chain-arduino-shield.sch, control-chain.sch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]
2015-06-25 sch: setting up footprints
    [arduino-connectors.sch]
2015-06-26 adding footprint to local project directory (submodule)
    [arduino-connectors.sch, control-chain.sch, perfboard.sch]
2015-06-26 BOM generated
    [control-chain-arduino-shield.csv]
2015-06-26 importing arduino uno layout template
    [control-chain-arduino-shield.kicad_pcb]
2015-06-26 sch: fixing footprints and renaming some connectors
    [arduino-connectors.sch, control-chain.sch, perfboard.sch]
2015-06-26 pcb: importing netlist
    [control-chain-arduino-shield.kicad_pcb]
2015-06-26 pcb: RJ45 connectors placed
    [control-chain-arduino-shield.kicad_pcb]
2015-06-26 sch: adjusting perfboard
    [perfboard.sch]
2015-06-26 pcb: initial placement of components
    [control-chain-arduino-shield.kicad_pcb]
2015-06-26 pcb: setting design rules
    [control-chain-arduino-shield.kicad_pcb]
2015-06-26 pcb: design almost done, missing 2 or 3 tracks
    [control-chain-arduino-shield.kicad_pcb]
2015-06-29 sch: fixing connectors I/Os pinout
    [arduino-connectors.sch, control-chain.sch, perfboard.sch]
2015-06-29 pcb: all tracks done + silkscreen of I/Os
    [control-chain-arduino-shield.kicad_pcb]
2015-06-29 pcb: adjusting holes
    [control-chain-arduino-shield.kicad_pcb]
2015-06-29 BOM updated
    [control-chain-arduino-shield.csv]
2015-06-29 removing old stuff
    [BOM-mod-arduino-shield.xls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]
2015-09-29 sch: changing input voltage from +9V to +12V
    [arduino-connectors.sch, control-chain.sch, perfboard.sch]
2015-10-15 sch: fixing MOSFET + new BOM exported
    [arduino-connectors.sch, control-chain-arduino-shield.csv, control-chain.sch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]
2015-10-15 pcb: updating layout
    [control-chain-arduino-shield.kicad_pcb]
2015-10-17 adding board size
    [control-chain-arduino-shield.kicad_pcb]
2015-10-17 improving silkscreen
    [control-chain-arduino-shield.kicad_pcb]
2015-10-17 panel created
    [control-chain-arduino-shield-panel-B_Cu.gbr, control-chain-arduino-shield-panel-B_Mask.gbr, control-chain-arduino-shield-panel-B_SilkS.gbr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]
2015-10-17 fixing user led voltage
    [arduino-connectors.sch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]
2016-06-08 fix RJ45 pinout
    [control-chain.sch]
2016-06-08 fix all DRC issues
    [arduino-connectors.sch, control-chain.sch, perfboard.sch]
2016-06-08 add perfboard footprint
2016-06-08 replace multiple headers by perfboard
    [perfboard.sch]
2016-06-08 fix pin name (vin)
    [perfboard.sch]
2016-06-09 connect all voltage inputs pins
    [arduino-connectors.sch, control-chain.sch]
2016-06-09 update layout to last schematic
    [control-chain-arduino-shield.kicad_pcb]
2016-06-17 change RJ45 connector
    [control-chain-arduino-shield.kicad_pcb, control-chain.sch]
2016-06-17 add header MPN to BOM
    [arduino-connectors.sch, control-chain-arduino-shield.csv]
2016-06-17 add local footprint library
2016-07-12 remove panel gerber files
    [control-chain-arduino-shield-panel-B_Cu.gbr, control-chain-arduino-shield-panel-B_Mask.gbr, control-chain-arduino-shield-panel-B_SilkS.gbr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]
2016-07-12 update BOM
    [control-chain-arduino-shield.csv]
2016-07-12 export gerber
    [control-chain-arduino-shield-B.CrtYd.gbr, control-chain-arduino-shield-B.Cu.gbr, control-chain-arduino-shield-B.Fab.gbr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]
2016-07-12 remove panel project files
    [control-chain-arduino-shield-panel.kicad_pcb]
2017-04-26 generate schematic pdf
2018-05-18 add enable circuit for RE pin
    [arduino-connectors.sch, control-chain-arduino-shield.csv, control-chain-arduino-shield.kicad_pcb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]
2018-05-18 update footprints (remove silkscreen from pads)
    [control-chain-arduino-shield.kicad_pcb]
2018-05-18 move led position
    [control-chain-arduino-shield.kicad_pcb]
2018-05-18 update gerber and pdf files
    [control-chain-arduino-shield-B.CrtYd.gbr, control-chain-arduino-shield-B.Cu.gbr, control-chain-arduino-shield-B.Fab.gbr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]
2021-11-10 Update README.md
    https://forum.kicad.info/t/warning-avoid-all-links-to-kicad-pcb-org-use-kicad-org/31521
